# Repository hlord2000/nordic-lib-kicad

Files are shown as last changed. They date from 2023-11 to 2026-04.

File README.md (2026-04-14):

# Nordic Semiconductor KiCad Library




---
# A KiCad 10 library for all modern Nordic Semiconductor parts.
<p align="center">
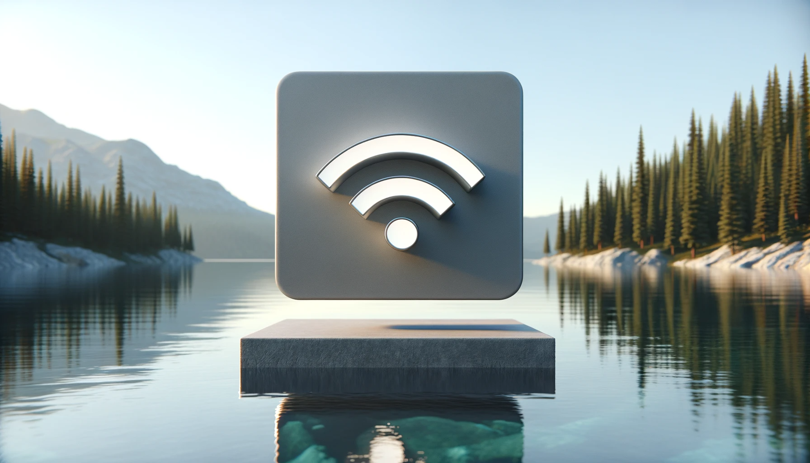
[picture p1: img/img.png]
centered image
  
</p>

KLC compliance is established using KiCad's official scripts within the "kicad-library-utils" folder and the "lib_check.sh" script

Compliance for the purposes of this library is defined as zero errors for footprints and symbols. Reasonable warnings about pin position or names may be accepted.

## Installation instructions

Open the KiCad Plugin and Content Manager (PCM), click "Manage..." in the top right, and add the following URL to your list of repositories:
```
https://raw.githubusercontent.com/hlord2000/hlord2000-kicad-repository/main/repository.json
```
Then, using the dropdown in the PCM, switch to "hlord2000's KiCad Repository" and click on the "Libraries" tab.

## Seeking pull-requests for any footprint/symbol/reference design block/3D model marked 🚧

 # nRF9 series - Cellular

| | Symbol | Footprint | Reference Design Block | 3D Model | KLC Compliant |
|---|---|---|---|---|---|
| [nRF9151](https://www.nordicsemi.com/products/nrf9151) LGA |✅|✅|🚧|✅|🚧|
| [nRF9161](https://www.nordicsemi.com/products/nrf9161) LGA |✅|✅|🚧|✅|🚧|
| [nRF9160](https://www.nordicsemi.com/products/nrf9160) LGA |✅|✅|🚧|✅|🚧|

 # nRF7 series - Wi-Fi

| | Symbol | Footprint | Reference Design Block | 3D Model | KLC Compliant |
|---|---|---|---|---|---|
| [nRF7002](https://www.nordicsemi.com/products/nrf7002) QFN |✅|✅|🚧|✅|🚧| 
| [nRF7002](https://www.nordicsemi.com/products/nrf7002) WLCSP |✅|✅|🚧|✅|🚧| 
| [nRF7001](https://www.nordicsemi.com/products/nrf7001) QFN |✅|✅|🚧|✅|🚧| 
| [nRF7000](https://www.nordicsemi.com/products/nrf7000) QFN |✅|✅|🚧|✅|🚧| 

# nRF54L series - Bluetooth Low Energy

| | Symbol | Footprint | Reference Design Block | 3D Model | KLC Compliant |
|---|---|---|---|---|---|
| [nRF54LM20A](https://www.nordicsemi.com/Products/nRF54LM20A) QFN-52 |✅|✅|✅|✅|🚧| 
| [nRF54LM20A](https://www.nordicsemi.com/Products/nRF54LM20A) FCCSP |✅|✅|✅|✅|🚧| 
| [nRF54L15](https://www.nordicsemi.com/products/nrf54l15) QFN-52 |✅|✅|✅|✅|🚧| 
| [nRF54L15](https://www.nordicsemi.com/products/nrf54l15) QFN-48 |✅|✅|✅|✅|🚧| 
| [nRF54L15](https://www.nordicsemi.com/products/nrf54l15) QFN-40 |✅|✅|✅|✅|🚧| 
| [nRF54L15](https://www.nordicsemi.com/products/nrf54l15) WLCSP |✅|✅|✅|✅|🚧| 
| [nRF54L10](https://www.nordicsemi.com/products/nrf54l10) QFN-52 |✅|✅|✅|✅|🚧| 
| [nRF54L10](https://www.nordicsemi.com/products/nrf54l10) QFN-48 |✅|✅|✅|✅|🚧| 
| [nRF54L10](https://www.nordicsemi.com/products/nrf54l10) QFN-40 |✅|✅|✅|✅|🚧| 
| [nRF54LV10A](https://www.nordicsemi.com/products/nrf54lv10) CSP-29 |✅|✅|🚧|✅|🚧| 
| [nRF54LV10A](https://www.nordicsemi.com/products/nrf54lv10) QFN-48 |✅|✅|🚧|✅|🚧| 
| [nRF54LS05A](https://www.nordicsemi.com/Products/nRF54LS05A) QFN-48 |✅|✅|🚧|✅|🚧| 
| [nRF54LS05B](https://www.nordicsemi.com/Products/nRF54LS05B) QFN-48 |✅|✅|🚧|✅|🚧| 
| [nRF54L05](https://www.nordicsemi.com/products/nrf54l05) QFN-52 |✅|✅|✅|✅|🚧| 
| [nRF54L05](https://www.nordicsemi.com/products/nrf54l05) QFN-48 |✅|✅|✅|✅|🚧| 
| [nRF54L05](https://www.nordicsemi.com/products/nrf54l05) QFN-40 |✅|✅|✅|✅|🚧| 

 # nRF53 series - Bluetooth Low Energy

| | Symbol | Footprint | Reference Design Block | 3D Model | KLC Compliant |
|---|---|---|---|---|---|
| [nRF5340](https://www.nordicsemi.com/products/nrf5340) aQFN |✅|✅|🚧|🚧|🚧| 
| [nRF5340](https://www.nordicsemi.com/products/nrf5340) WLCSP |✅|✅|🚧|🚧|🚧| 

 # nRF52 series - Bluetooth Low Energy

| | Symbol | Footprint | Reference Design Block | 3D Model | KLC Compliant |
|---|---|---|---|---|---|
| [nRF52840](https://www.nordicsemi.com/products/nrf52840) aQFN |✅|✅|🚧|✅|🚧| 
| [nRF52840](https://www.nordicsemi.com/products/nrf52840) WLCSP |✅|✅|🚧|🚧|🚧| 
| [nRF52840](https://www.nordicsemi.com/products/nrf52840) QFN |✅|✅|🚧|✅|🚧| 
| [nRF52833](https://www.nordicsemi.com/products/nrf52833) aQFN |✅|✅|🚧|🚧|🚧| 
| [nRF52833](https://www.nordicsemi.com/products/nrf52833) WLCSP |✅|✅|🚧|🚧|🚧| 
| [nRF52833](https://www.nordicsemi.com/products/nrf52833) QFN |✅|✅|🚧|✅|🚧| 
| [nRF52832](https://www.nordicsemi.com/products/nrf52832) WLCSP |✅|✅|🚧|🚧|🚧| 
| [nRF52832](https://www.nordicsemi.com/products/nrf52832) QFN |✅|✅|🚧|✅|🚧| 
| [nRF52820](https://www.nordicsemi.com/products/nrf52820) WLCSP |✅|✅|🚧|🚧|🚧| 
| [nRF52820](https://www.nordicsemi.com/products/nrf52820) QFN |✅|✅|🚧|✅|🚧| 
| [nRF52811](https://www.nordicsemi.com/products/nrf52811) WLCSP |✅|✅|🚧|✅|🚧| 
| [nRF52811](https://www.nordicsemi.com/products/nrf52811) QFN-32 |✅|✅|🚧|✅|🚧| 
| [nRF52811](https://www.nordicsemi.com/products/nrf52811) QFN-48 |✅|✅|🚧|✅|🚧| 
| [nRF52810](https://www.nordicsemi.com/products/nrf52810) WLCSP |✅|✅|🚧|✅|🚧| 
| [nRF52810](https://www.nordicsemi.com/products/nrf52810) QFN-32 |✅|✅|🚧|✅|🚧| 
| [nRF52810](https://www.nordicsemi.com/products/nrf52810) QFN-48 |✅|✅|🚧|✅|🚧| 
| [nRF52805](https://www.nordicsemi.com/products/nrf52805) WLCSP |✅|✅|🚧|✅|🚧| 

 # nRF52 series - Modules

| | Symbol | Footprint | Reference Design Block | 3D Model | KLC Compliant |
|---|---|---|---|---|---|
| [E73-2G4M08S1C](https://www.ebyte.com/product-view-news.html?id=787) LGA module |✅|✅|🚧|✅|🚧|
| [ISP1907-LL](https://www.insightsip.com/products/bluetooth-low-energy/isp1907) LGA module |✅|✅|🚧|✅|🚧|

 # nRF21 series - PA + LNA ICs

| | Symbol | Footprint | Reference Design Block | 3D Model | KLC Compliant |
|---|---|---|---|---|---|
| [nRF21540](https://www.nordicsemi.com/products/nrf21540) QFN |✅|✅|🚧|✅|✅| 

 # nRF53 series - Modules

| | Symbol | Footprint | Reference Design Block | 3D Model | KLC Compliant |
|---|---|---|---|---|---|
| [E83-2G4M03S](https://www.ebyte.com/product-view-news.html?id=1307) LGA module |✅|✅|🚧|✅|🚧|
| [ISP2053-AX](https://www.insightsip.com/products/bluetooth-low-energy-and-802-15-4/isp2053) LGA module |✅|✅|🚧|✅|🚧|

 # nRF54 series - Modules

| | Symbol | Footprint | Reference Design Block | 3D Model | KLC Compliant |
|---|---|---|---|---|---|
| BC15C LGA module |✅|✅|🚧|✅|🚧|
| BC15M LGA module |✅|✅|🚧|✅|🚧|
| BL54L15-453-000xxx LGA module |✅|✅|🚧|✅|🚧|
| BL54L10-453-000xxx LGA module |✅|✅|🚧|✅|🚧|
| BM15x LGA module |✅|✅|🚧|✅|🚧|
| BM20x LGA module |✅|✅|🚧|✅|🚧|

 # nPM Power Management ICs

| | Symbol | Footprint | Reference Design Block | 3D Model | KLC Compliant |
|---|---|---|---|---|---|
| [nPM6001](https://www.nordicsemi.com/products/nPM6001) WLCSP |✅|✅|🚧|🚧|✅| 
| [nPM2100](https://www.nordicsemi.com/products/nPM2100) WLCSP |✅|✅|🚧|✅|✅| 
| [nPM2100](https://www.nordicsemi.com/products/nPM2100) QFN |✅|✅|🚧|✅|✅| 
| [nPM1300](https://www.nordicsemi.com/products/nPM1300) WLCSP |✅|✅|🚧|🚧|✅| 
| [nPM1300](https://www.nordicsemi.com/products/nPM1300) QFN |✅|✅|🚧|✅|✅| 
| [nPM1100](https://www.nordicsemi.com/products/nPM1100) WLCSP |✅|✅|🚧|🚧|✅| 
| [nPM1100](https://www.nordicsemi.com/products/nPM1100) QFN |✅|✅|🚧|✅|✅|

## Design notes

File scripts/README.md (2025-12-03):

# Nordic Symbol Utilities

Utilities for parsing and generating KiCad symbols using the kiutils library.

## Setup

```bash
# From the repository root
uv venv
source .venv/bin/activate
uv pip install kiutils
```

## Usage

### List symbols in a library

```bash
python scripts/symbol_utils.py parse symbols/nordic-lib-kicad-nrf52.kicad_sym --list
```

### Parse a specific symbol

```bash
python scripts/symbol_utils.py parse symbols/nordic-lib-kicad-nrf52.kicad_sym --symbol nRF52805-CAXX --verbose
```

### Extract pin table

```bash
# Table format (default)
python scripts/symbol_utils.py pins symbols/nordic-lib-kicad-nrf52.kicad_sym --symbol nRF52805-CAXX

# CSV format
python scripts/symbol_utils.py pins symbols/nordic-lib-kicad-nrf52.kicad_sym --symbol nRF52805-CAXX --format csv

# JSON format
python scripts/symbol_utils.py pins symbols/nordic-lib-kicad-nrf52.kicad_sym --symbol nRF52805-CAXX --format json
```

### Extract complete symbol definition to JSON

```bash
python scripts/symbol_utils.py extract symbols/nordic-lib-kicad-nrf52.kicad_sym --symbol nRF52805-CAXX --output my_symbol.json
```

### Generate a symbol from JSON definition

```bash
python scripts/symbol_utils.py generate my_symbol.json --output my_symbol.kicad_sym
```

### Validate a symbol against KLC rules

```bash
python scripts/symbol_utils.py validate symbols/nordic-lib-kicad-nrf52.kicad_sym --symbol nRF52805-CAXX
```

## JSON Definition Format

The symbol definition JSON format for generation:

```json
{
  "name": "MyChip",
  "reference": "U",
  "footprint": "Package_QFP:LQFP-48_7x7mm_P0.5mm",
  "datasheet": "https://example.com/datasheet.pdf",
  "description": "My example chip",
  "keywords": "example chip mcu",
  "fp_filters": "LQFP?48*",
  "left_pins": [
    {
      "number": "1",
      "name": "PA0",
      "electrical_type": "bidirectional",
      "graphical_style": "line",
      "hidden": false,
      "alternates": [
        {"name": "ADC0", "electrical_type": "input", "graphical_style": "line"}
      ]
    }
  ],
  "right_pins": [],
  "top_pins": [
    {"number": "10", "name": "VDD", "electrical_type": "power_in", "graphical_style": "line", "hidden": false, "alternates": []}
  ],
  "bottom_pins": [
    {"number": "11", "name": "VSS", "electrical_type": "power_in", "graphical_style": "line", "hidden": false, "alternates": []}
  ]
}
```

### Pin Electrical Types

- `input` - Input pin
- `output` - Output pin
- `bidirectional` - Bidirectional I/O pin
- `power_in` - Power input (VDD, VCC)
- `power_out` - Power output (voltage regulator output)
- `passive` - Passive pin (resistors, capacitors, ground pads)
- `open_collector` - Open collector output
- `open_emitter` - Open emitter output
- `tri_state` - Tri-state output
- `unspecified` - Unspecified type
- `no_connect` - Not connected

### Pin Graphical Styles

- `line` - Standard line
- `inverted` - Inverted (bubble)
- `clock` - Clock input
- `inverted_clock` - Inverted clock
- `input_low` - Active low input
- `clock_low` - Active low clock
- `output_low` - Active low output
- `edge_clock_high` - Edge-triggered clock
- `non_logic` - Non-logic pin

## KLC Compliance

Generated symbols are designed to be KLC (KiCad Library Convention) compliant:

- S3.3: 10mil (0.254mm) stroke width on outlines
- S4.1: All pins on 100mil (2.54mm) grid
- Proper pin grouping by function (left/right/top/bottom)
- Standard property fields (Reference, Value, Footprint, Datasheet, Description)

Note: The KLC checker in kicad-library-utils may report some format warnings due to differences in KiCad version output formats. The generated symbols are functionally correct and compatible with KiCad.

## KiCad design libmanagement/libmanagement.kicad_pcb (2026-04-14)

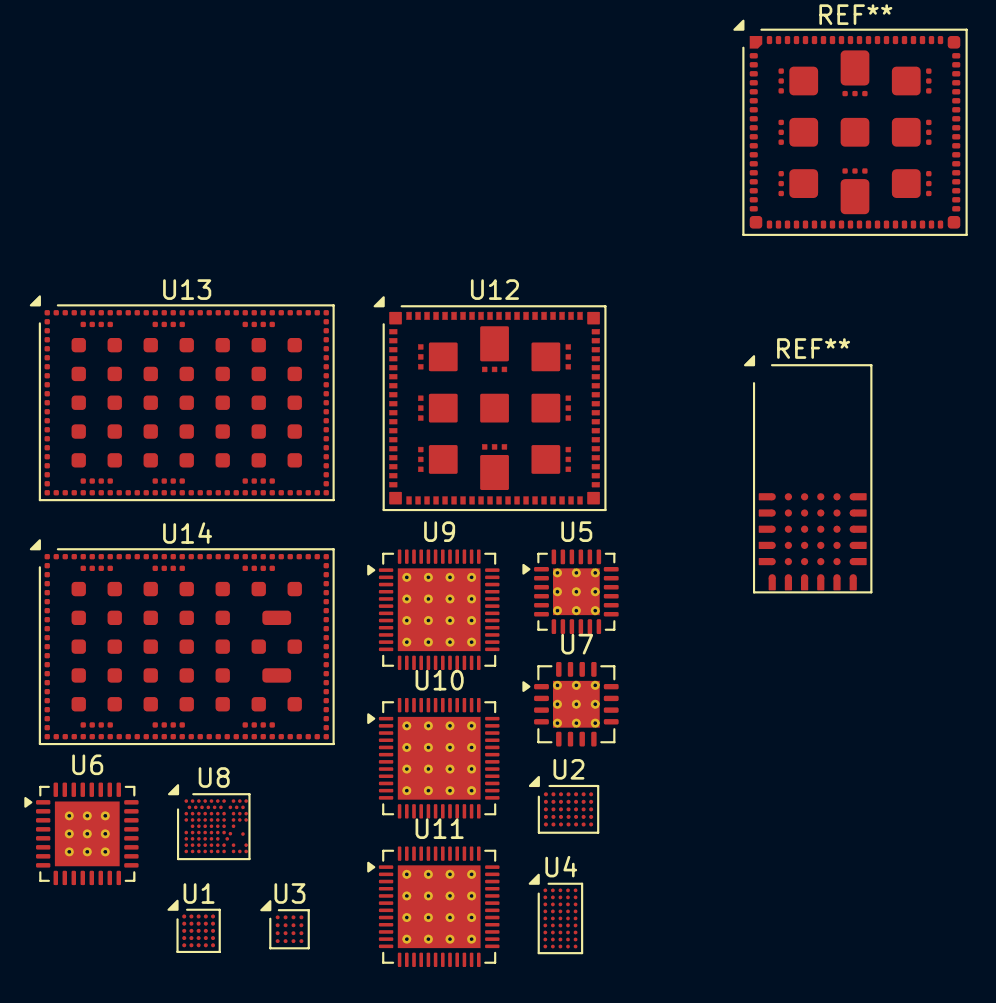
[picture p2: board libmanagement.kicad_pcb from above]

Board: 2 copper layers, 14 parts (0 on the bottom side), 21 nets, no tracks yet.

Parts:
U1: nPM1100-CAXX; BGA-25_5x5_2.075x2.075mm
U2: nPM1300-CAXX; BGA-35_7x5_3.077x2.3775mm
U3: nPM2100-CAXX; BGA-16_4x4_1.9175x1.8975mm
U4: nPM6001-CAXX; BGA-45_5x9_2.175x3.635mm
U5: nPM1100-QDXX; QFN-24-1EP_4x4mm_P0.5mm_EP2.6x2.6mm_ThermalVias
U6: nPM1300-QEXX; QFN-32-1EP_5x5mm_P0.5mm_EP3.6x3.6mm_ThermalVias
U7: nPM2100-QEXX; UQFN-16-1EP_4x4mm_P0.65mm_EP2.6x2.6mm_ThermalVias
U8: nRF7002-CEXX; BGA-90_10x9_3.7495x3.385mm
U9: nRF7000-QFXX; QFN-48-1EP_6x6mm_P0.4mm_EP4.6x4.6mm_ThermalVias
U10: nRF7001-QFXX; QFN-48-1EP_6x6mm_P0.4mm_EP4.6x4.6mm_ThermalVias
U11: nRF7002-QFXX; QFN-48-1EP_6x6mm_P0.4mm_EP4.6x4.6mm_ThermalVias
U12: nRF9151-LAXX; LGA_9151_12.1x11.1mm
U13: nRF9160-SIXX; LGA_9160_16.0x10.5mm
U14: nRF9161-SIXX; LGA_9161_16.0x10.5mm

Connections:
AVSS2: U7.11 (AVSS2), U7.16 (PVSS), U7.17 (EP)
unnamed: U1.D1 (VBAT), U1.D2 (VBAT)
unnamed: U1.B1 (VBUS), U1.B2 (VBUS)
unnamed: U1.A5 (VSS), U1.C4 (AVSS), U1.C5 (AVSS)
unnamed: U1.C1 (VSYS), U1.C2 (VSYS)
unnamed: U2.D1 (VBAT), U2.D2 (VBAT)
unnamed: U2.B1 (VBUS), U2.B2 (VBUS)
unnamed: U2.C1 (VSYS), U2.C2 (VSYS)
unnamed: U3.A4 (PVSS), U3.B1 (AVSS1), U3.B2 (AVSS2)
unnamed: U4.A3 (AVSS1_2), U4.B3 (RESERVED), U4.E5 (RESERVED), U4.F1 (VSS), U4.F2 (AVSS_ANA), U4.F4 (RESERVED), U4.G3 (RESERVED), U4.H2 (RESERVED), U4.H3 (AVSS0)
unnamed: U4.F3 (VIN_ANA), U4.G1 (VIN)
unnamed: U4.B4 (RESERVED), U4.C3 (RESERVED), U4.E4 (RESERVED), U4.G5 (VO0_IN), U4.H5 (VO0)
unnamed: U5.4 (AVSS), U5.25 (AVSS)
unnamed: U7.14 (VINT), U7.15 (VINT)
unnamed: U8.A1 (VSS), U8.A7 (GND), U8.A13 (GND), U8.A18 (GND), U8.A20 (GND), U8.C5 (GND), U8.C7 (GND), U8.C9 (GND), U8.C11 (GND), U8.C13 (GND), U8.D1 (GND), U8.D5 (GND), U8.D7 (GND), U8.D9 (GND), U8.D11 (GND), U8.D13 (GND), U8.D16 (GND), U8.D20 (GND), U8.E3 (GND), U8.E5 (GND), U8.E7 (GND), U8.E9 (GND), U8.E11 (GND), U8.E13 (GND), U8.F7 (GND), U8.F9 (GND), U8.F11 (GND), U8.F13 (GND), U8.H20 (GND), U8.J1 (BUCKVSSS), U8.J7 (GND), U8.K1 (BUCKVSS), U8.K20 (GND), U8.L3 (GND), U8.L9 (GND), U8.L18 (GND)
unnamed: U9.27 (BUCKVSS), U9.28 (BUCKVSS), U9.47 (VSS), U9.49 (EP)
unnamed: U10.8 (PAVDD1), U10.27 (BUCKVSS), U10.28 (BUCKVSS), U10.47 (VSS), U10.49 (EP)
unnamed: U11.27 (BUCKVSS), U11.28 (BUCKVSS), U11.47 (VSS), U11.49 (EP)
unnamed: U12.1 (GND), U12.7 (GND), U12.13 (GND), U12.15 (GND), U12.20 (GND), U12.25 (GND), U12.30 (GND), U12.34 (GND), U12.36 (GND), U12.38 (GND), U12.39 (GND), U12.40 (GND), U12.41 (GND), U12.43 (GND), U12.46 (GND), U12.51 (GND), U12.55 (GND), U12.60 (GND), U12.66 (GND), U12.71 (GND), U12.76 (GND), U12.105 (GND), U12.106 (GND), U12.107 (GND), U12.108 (GND), U12.109 (GND), U12.110 (GND), U12.111 (GND), U12.112 (GND), U12.113 (GND)
unnamed: U13.1 (GND_Shield), U13.5 (GND_Shield), U13.6 (GND_Shield), U13.7 (GND_Shield), U13.8 (GND_Shield), U13.9 (GND_Shield), U13.11 (GND_Shield), U13.14 (GND_Shield), U13.17 (GND_Shield), U13.21 (GND_Shield), U13.27 (GND_Shield), U13.31 (GND_Shield), U13.36 (GND_Shield), U13.41 (GND_Shield), U13.44 (GND_Shield), U13.47 (GND_Shield), U13.50 (GND_Shield), U13.52 (GND_Shield), U13.56 (GND_Shield), U13.60 (GND_Shield), U13.62 (GND_Shield), U13.63 (GND_Shield), U13.65 (GND_Shield), U13.66 (GND_Shield), U13.68 (GND_Shield), U13.69 (GND_Shield), U13.72 (GND_Shield), U13.74 (GND_Shield), U13.75 (GND_Shield), U13.76 (GND_Shield), U13.77 (GND_Shield), U13.78 (GND_Shield), U13.79 (GND_Shield), U13.80 (GND_Shield), U13.81 (GND_Shield), U13.82 (GND_Shield), U13.85 (GND_Shield), U13.90 (GND_Shield), U13.94 (GND_Shield), U13.98 (GND_Shield), U13.103 (VSS)
unnamed: U14.1 (GND_Shield), U14.5 (GND_Shield), U14.6 (GND_Shield), U14.7 (GND_Shield), U14.8 (GND_Shield), U14.9 (GND_Shield), U14.11 (GND_Shield), U14.14 (GND_Shield), U14.17 (GND_Shield), U14.21 (GND_Shield), U14.27 (GND_Shield), U14.31 (GND_Shield), U14.36 (GND_Shield), U14.41 (GND_Shield), U14.44 (GND_Shield), U14.47 (GND_Shield), U14.50 (GND_Shield), U14.52 (GND_Shield), U14.56 (GND_Shield), U14.60 (GND_Shield), U14.62 (GND_Shield), U14.63 (GND_Shield), U14.65 (GND_Shield), U14.66 (GND_Shield), U14.68 (GND_Shield), U14.69 (GND_Shield), U14.72 (GND_Shield), U14.74 (GND_Shield), U14.75 (GND_Shield), U14.76 (GND_Shield), U14.77 (GND_Shield), U14.78 (GND_Shield), U14.79 (GND_Shield), U14.80 (GND_Shield), U14.81 (GND_Shield), U14.82 (GND_Shield), U14.85 (GND_Shield), U14.90 (GND_Shield), U14.94 (GND_Shield), U14.98 (GND_Shield), U14.103 (VSS)

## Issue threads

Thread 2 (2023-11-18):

KiCad 7 unable to open file because it was created with a more recent version

FARLY7, 2023-11-18:
Installed the latest stable release of KiCad 7 (7.0.9), then followed the latest install instructions in the `main` branch. Received this error when loading the library in the schematic editor:

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

FARLY7, 2023-11-18:
Installing the latest nightly build worked. I think you should generate the library using the latest _stable_ release, not _nightly_?

hlord2000, 2023-12-09:
Closed by #5

Closed 2023-12-09.

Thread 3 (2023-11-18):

nRF9160-SIXX footprint is missing when README indicates it's included

FARLY7, 2023-11-18:
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

FARLY7, 2023-11-18:
It seems the footprint is there within the library, it just needs to be manually assigned?

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

However, after doing so, I get the following error in the board editor:

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

hlord2000, 2023-11-19:
Thank you for the issue reports! #2 as well! I will look into this over the next week or so.

hlord2000, 2023-12-09:
Fixed by #6

Closed 2023-12-09.

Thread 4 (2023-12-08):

Footprint for nRF9161

Arakistech, 2023-12-08:
Could you please add footprint for nRF9161? It is slightly different from nRF9160.

hlord2000, 2023-12-08:
Thanks for the issue! The 9161 is not yet available publicly--I cannot add footprints until they are available without NDA.

hlord2000, 2024-01-19:
Closed w/ https://github.com/hlord2000/nordic-lib-kicad/commit/e9b5a4e1483e48f4504e956a48b8dacd965c80cc

Closed 2024-01-19.

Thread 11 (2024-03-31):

Errors in nPM1100-QDXX symbol/footprint (due to errors in the product specification)

jeffc, 2024-03-31:
There are two errors in the footprint for the nPM1100-QDXX, which appear to be due to errors in the product specification which have not yet been corrected by Nordic:

 * Pin 4 should be labelled `AVSS` and connected to ground, not `NC`. This is an error in the pinout section on p.48 of the product specification. It is correct in the example schematics on pages 52, 53, and 54.
 * Pin 3 should be labelled `VOUTBSET0`, not `VOUTBSET2` (this is apparently a typo in the pinout sheet; there is no pin `VOUTBSET2`).

These errors have been acknowledged multiple times by Nordic engineers in the devzone ([example 1](https://devzone.nordicsemi.com/f/nordic-q-a/102701/npm1100-datasheet-pin-out), [example 2](https://devzone.nordicsemi.com/f/nordic-q-a/105055/npm1100-qda-pinout-documentation-fixed), [example 3](https://devzone.nordicsemi.com/f/nordic-q-a/106364/npm1100-product-specification-v1-3-errors)), but have not yet been corrected.

Closed 2024-04-01.

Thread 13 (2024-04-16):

Electrical type of pins is `Unspecified`

simplexion-blechschmidt, 2024-04-16:
Due to all pins on the (e.g. on the nRF9160-SIXX symbol) being `Unspecified`, the ERC is showing a lot of warnings and errors.
NRF provides a [pin assignment table](https://docs.nordicsemi.com/bundle/ps_nrf9160/page/pin.html) that also lists the function.

hlord2000, 2024-04-19:
Closed by
https://github.com/hlord2000/nordic-lib-kicad/pull/14

Closed 2024-04-19.

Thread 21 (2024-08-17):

only bga footprint？

yangxing844, 2024-08-17:
Hi, first of all, thank you for this  awesome collection! however I don't seem to find other footprint other than bga? the readme says QFN is supported, however I can not find it

hlord2000, 2024-08-17:
Hello, I'll take a look at this. All of the QFNs use KiCAD standard footprints.

hlord2000, 2024-09-24:
Refer to KiCAD 8 standard library of footprints

Closed 2024-09-24.

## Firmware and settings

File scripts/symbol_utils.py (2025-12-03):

#!/usr/bin/env python3
"""
Symbol Utilities for Nordic KiCad Library

This module provides utilities for parsing and generating KiCad symbols
using the kiutils library. It enables:
- Parsing existing symbols to extract pin tables
- Generating new symbols from pin table definitions
- Analyzing symbol structure for KLC compliance

Usage:
    # Parse a symbol and show its structure
    python symbol_utils.py parse symbols/nordic-lib-kicad-nrf52.kicad_sym --symbol nRF52805-CAXX

    # Extract pin table as CSV
    python symbol_utils.py pins symbols/nordic-lib-kicad-nrf52.kicad_sym --symbol nRF52805-CAXX --format csv

    # Generate a symbol from a pin table JSON
    python symbol_utils.py generate pin_table.json --output output.kicad_sym

    # Validate a symbol against KLC rules
    python symbol_utils.py validate symbols/nordic-lib-kicad-nrf52.kicad_sym --symbol nRF52805-CAXX
"""

import argparse
import json
import sys
import csv
import io
import subprocess
from dataclasses import dataclass, field, asdict
from pathlib import Path
from typing import Optional, List, Dict, Any, Tuple

from kiutils.symbol import SymbolLib, Symbol, SymbolPin, SymbolAlternativePin
from kiutils.items.common import Position, Effects, Font, Property, Fill, Stroke, Justify
from kiutils.items.syitems import SyRect


# Constants for symbol layout (KLC compliant)
# KLC S4.1: Pins must be on 100mil (2.54mm) grid
PIN_LENGTH = 2.54
PIN_SPACING = 2.54  # 100mil grid spacing
FONT_SIZE = 1.27
# KLC S3.3: Symbol outline should be 10mil (0.254mm)
RECT_STROKE_WIDTH = 0.254  # 10mil stroke width for KLC compliance
RECT_STROKE_TYPE = "default"
GRID_SIZE = 2.54  # 100mil grid


def snap_to_grid(value: float, grid: float = GRID_SIZE) -> float:
    """Snap a value to the nearest grid point (100mil by default)."""
    return round(value / grid) * grid


def parse_pin_name(name: str) -> Tuple[str, int, int]:
    """
    Parse a pin name into sortable components.

    Returns tuple of (category, port, pin_num) for sorting.
    Categories (lower number = higher priority/position):
    - 0: Crystal (XC1, XC2, XL1, XL2)
    - 1: GPIO Port 1 (P1.xx)
    - 2: GPIO Port 0 (P0.xx)
    - 3: GPIO Port 2+ (P2.xx, etc.)
    - 4: Antenna (ANT)
    - 5: Debug (RESET, SWDIO, SWDCLK)
    - 6: Power (VDD, VDDL, VSS, DCC)
    - 7: Decoupling (DEC*, CFLY*)
    - 9: Other
    """
    import re

    name_upper = name.upper().replace('~{', '').replace('}', '')

    # Crystal pins
    if name_upper.startswith('XC') or name_upper.startswith('XL'):
        match = re.search(r'(\d+)', name)
        num = int(match.group(1)) if match else 0
        return (0, 0, num)

    # GPIO pins - P<port>.<pin>
    gpio_match = re.match(r'P(\d+)\.(\d+)', name)
    if gpio_match:
        port = int(gpio_match.group(1))
        pin = int(gpio_match.group(2))
        # P1 first (category 1), then P0 (category 2), then P2+ (category 3)
        if port == 1:
            return (1, port, pin)
        elif port == 0:
            return (2, port, pin)
        else:
            return (3, port, pin)

    # Antenna
    if name_upper == 'ANT':
        return (4, 0, 0)

    # Debug pins
    if name_upper in ('RESET', 'SWDIO', 'SWDCLK', 'SWO'):
        order = {'RESET': 0, 'SWDIO': 1, 'SWDCLK': 2, 'SWO': 3}
        return (5, 0, order.get(name_upper, 99))

    # Power pins
    if name_upper.startswith('VDD') or name_upper == 'DCC':
        return (6, 0, 0 if name_upper.startswith('VDD') else 1)
    if name_upper.startswith('VSS'):
        return (6, 1, 0)

    # Decoupling caps
    if name_upper.startswith('DEC') or name_upper.startswith('CFLY'):
        order = {'DECRF': 0, 'DECA': 1, 'DECB': 2, 'DECD': 3, 'CFLYL': 4, 'CFLYH': 5}
        return (7, 0, order.get(name_upper, 99))

    # Everything else
    return (9, 0, 0)


def sort_pins_by_name(pins: List['PinDefinition']) -> List['PinDefinition']:
    """Sort pins by their name according to Nordic convention."""
    return sorted(pins, key=lambda p: parse_pin_name(p.name))


def parse_pin_number(number: str) -> Tuple[bool, int, str]:
    """
    Parse a pin number for sorting.

    Returns tuple of (is_numeric, numeric_value, alpha_part) for sorting.
    Handles both numeric (1, 2, 48) and BGA-style (A1, B2, F5) pin numbers.
    """
    import re

    # Try pure numeric first
    if number.isdigit():
        return (True, int(number), '')

    # Try BGA style (letter + number)
    match = re.match(r'([A-Z]+)(\d+)', number.upper())
    if match:
        letter_part = match.group(1)
        num_part = int(match.group(2))
        # Convert letter to number (A=0, B=1, etc.) for sorting
        letter_val = sum((ord(c) - ord('A')) * (26 ** i)
                        for i, c in enumerate(reversed(letter_part)))
        return (False, letter_val * 100 + num_part, letter_part)

    # Fallback
    return (False, 0, number)


def sort_pins_by_number(pins: List['PinDefinition']) -> List['PinDefinition']:
    """Sort pins by their pin number (numeric or BGA-style)."""
    return sorted(pins, key=lambda p: parse_pin_number(p.number))


@dataclass
class PinDefinition:
    """Represents a single pin definition for symbol generation."""
    number: str
    name: str
    electrical_type: str = "bidirectional"  # input, output, bidirectional, power_in, power_out, passive, etc.
    graphical_style: str = "line"  # line, inverted, clock, etc.
    hidden: bool = False
    alternates: List[Dict[str, str]] = field(default_factory=list)

    @classmethod
    def from_symbol_pin(cls, pin: SymbolPin) -> 'PinDefinition':
        """Create a PinDefinition from a kiutils SymbolPin."""
        alternates = []
        for alt in pin.alternatePins:
            alternates.append({
                'name': alt.pinName,
                'electrical_type': alt.electricalType,
                'graphical_style': alt.graphicalStyle
            })
        return cls(
            number=pin.number,
            name=pin.name,
            electrical_type=pin.electricalType,
            graphical_style=pin.graphicalStyle,
            hidden=pin.hide,
            alternates=alternates
        )

    def to_dict(self) -> Dict[str, Any]:
        """Convert to dictionary for JSON serialization."""
        return asdict(self)


@dataclass
class SymbolDefinition:
    """Represents a complete symbol definition for generation."""
    name: str
    reference: str = "U"
    footprint: str = ""
    datasheet: str = ""
    description: str = ""
    keywords: str = ""
    fp_filters: str = ""

    # Pin groups by side
    left_pins: List[PinDefinition] = field(default_factory=list)
    right_pins: List[PinDefinition] = field(default_factory=list)
    top_pins: List[PinDefinition] = field(default_factory=list)
    bottom_pins: List[PinDefinition] = field(default_factory=list)

    def to_dict(self) -> Dict[str, Any]:
        """Convert to dictionary for JSON serialization."""
        return {
            'name': self.name,
            'reference': self.reference,
            'footprint': self.footprint,
            'datasheet': self.datasheet,
            'description': self.description,
            'keywords': self.keywords,
            'fp_filters': self.fp_filters,
            'left_pins': [p.to_dict() for p in self.left_pins],
            'right_pins': [p.to_dict() for p in self.right_pins],
            'top_pins': [p.to_dict() for p in self.top_pins],
            'bottom_pins': [p.to_dict() for p in self.bottom_pins],
        }

    @classmethod
    def from_dict(cls, data: Dict[str, Any]) -> 'SymbolDefinition':
        """Create from dictionary (JSON deserialization)."""
        def parse_pins(pin_list: List[Dict]) -> List[PinDefinition]:
            return [PinDefinition(**p) for p in pin_list]

        return cls(
            name=data['name'],
            reference=data.get('reference', 'U'),
            footprint=data.get('footprint', ''),
            datasheet=data.get('datasheet', ''),
            description=data.get('description', ''),
            keywords=data.get('keywords', ''),
            fp_filters=data.get('fp_filters', ''),
            left_pins=parse_pins(data.get('left_pins', [])),
            right_pins=parse_pins(data.get('right_pins', [])),
            top_pins=parse_pins(data.get('top_pins', [])),
            bottom_pins=parse_pins(data.get('bottom_pins', [])),
        )


class SymbolParser:
    """Parses existing KiCad symbols and extracts information."""

    def __init__(self, library_path: str):
        self.library_path = Path(library_path)
        self.library: Optional[SymbolLib] = None

    def load(self) -> SymbolLib:
        """Load the symbol library."""
        if self.library is None:
            self.library = SymbolLib.from_file(str(self.library_path))
        return self.library

    def list_symbols(self) -> List[str]:
        """List all symbol names in the library."""
        lib = self.load()
        return [s.entryName for s in lib.symbols]

    def get_symbol(self, symbol_name: str) -> Optional[Symbol]:
        """Get a specific symbol by name."""
        lib = self.load()
        for symbol in lib.symbols:
            if symbol.entryName == symbol_name:
                return symbol
        return None

    def get_symbol_info(self, symbol_name: str) -> Dict[str, Any]:
        """Get detailed information about a symbol."""
        symbol = self.get_symbol(symbol_name)
        if symbol is None:
            return {}

        info = {
            'name': symbol.entryName,
            'in_bom': symbol.inBom,
            'on_board': symbol.onBoard,
            'properties': {},
            'units': [],
            'total_pins': 0,
        }

        # Extract properties
        for prop in symbol.properties:
            info['properties'][prop.key] = prop.value

        # Extract unit information
        for unit in symbol.units:
            unit_info = {
                'id': unit.libId,
                'pin_count': len(unit.pins),
                'graphic_items': len(unit.graphicItems),
            }
            info['units'].append(unit_info)
            info['total_pins'] += len(unit.pins)

        return info

    def extract_pins(self, symbol_name: str) -> List[PinDefinition]:
        """Extract all pins from a symbol."""
        symbol = self.get_symbol(symbol_name)
        if symbol is None:
            return []

        pins = []
        for unit in symbol.units:
            for pin in unit.pins:
                pins.append(PinDefinition.from_symbol_pin(pin))

        return pins

    def extract_pin_table(self, symbol_name: str) -> List[Dict[str, Any]]:
        """Extract pins as a flat table (for CSV export)."""
        pins = self.extract_pins(symbol_name)
        table = []
        for pin in pins:
            row = {
                'number': pin.number,
                'name': pin.name,
                'electrical_type': pin.electrical_type,
                'graphical_style': pin.graphical_style,
                'hidden': pin.hidden,
                'alternates': '; '.join([f"{a['name']}:{a['electrical_type']}" for a in pin.alternates])
            }
            table.append(row)
        return table

    def infer_pin_sides(self, symbol_name: str) -> Dict[str, List[PinDefinition]]:
        """Infer which side each pin belongs to based on position and angle."""
        symbol = self.get_symbol(symbol_name)
        if symbol is None:
            return {'left': [], 'right': [], 'top': [], 'bottom': []}

        sides = {'left': [], 'right': [], 'top': [], 'bottom': []}

        for unit in symbol.units:
            for pin in unit.pins:
                pin_def = PinDefinition.from_symbol_pin(pin)
                angle = pin.position.angle if pin.position.angle is not None else 0

                # Angle 0 = pointing right (pin on left side)
                # Angle 180 = pointing left (pin on right side)
                # Angle 90 = pointing up (pin on bottom)
                # Angle 270 = pointing down (pin on top)
                if angle == 0:
                    sides['left'].append(pin_def)
                elif angle == 180:
                    sides['right'].append(pin_def)
                elif angle == 90:
                    sides['bottom'].append(pin_def)
                elif angle == 270:
                    sides['top'].append(pin_def)
                else:
                    # Default to left for unusual angles
                    sides['left'].append(pin_def)

        return sides


class SymbolGenerator:
    """Generates KiCad symbols from definitions."""

    def __init__(self):
        self.generator_name = "nordic_symbol_utils"

    def create_symbol(self, definition: SymbolDefinition) -> Symbol:
        """Create a Symbol from a SymbolDefinition."""
        symbol = Symbol()
        symbol.entryName = definition.name
        symbol.inBom = True
        symbol.onBoard = True

        # Create standard properties
        symbol.properties = [
            self._create_property("Reference", definition.reference, 0, 0, 0),
            self._create_property("Value", definition.name, 0, -2.54, 1),
            self._create_property("Footprint", definition.footprint, 0, -5.08, 2, hide=True),
            self._create_property("Datasheet", definition.datasheet, 0, -7.62, 3, hide=True),
            self._create_property("Description", definition.description, 0, -10.16, 4, hide=True),
        ]

        if definition.keywords:
            symbol.properties.append(
                self._create_property("ki_keywords", definition.keywords, 0, 0, None, hide=True)
            )
        if definition.fp_filters:
            symbol.properties.append(
                self._create_property("ki_fp_filters", definition.fp_filters, 0, 0, None, hide=True)
            )

        # Create the unit with pins and rectangle
        unit = self._create_unit(definition)
        symbol.units.append(unit)

        return symbol

    def _create_property(self, key: str, value: str, x: float, y: float,
                        prop_id: Optional[int] = None, hide: bool = False) -> Property:
        """Create a property with standard formatting."""
        prop = Property()
        prop.key = key
        prop.value = value
        prop.id = prop_id
        prop.position = Position(X=x, Y=y, angle=0)
        prop.effects = Effects(
            font=Font(width=FONT_SIZE, height=FONT_SIZE),
            hide=hide
        )
        return prop

    def _create_unit(self, definition: SymbolDefinition, sort_pins: bool = True) -> Symbol:
        """Create a symbol unit with pins and graphics (KLC compliant).

        Args:
            definition: The symbol definition with pins organized by side
            sort_pins: If True, sort pins by name within each side
        """
        unit = Symbol()
        unit.entryName = definition.name
        unit.unitId = 1
        unit.styleId = 0

        # Sort pins by name if requested
        left_pins = sort_pins_by_name(definition.left_pins) if sort_pins else definition.left_pins
        right_pins = sort_pins_by_name(definition.right_pins) if sort_pins else definition.right_pins
        top_pins = sort_pins_by_name(definition.top_pins) if sort_pins else definition.top_pins
        bottom_pins = sort_pins_by_name(definition.bottom_pins) if sort_pins else definition.bottom_pins

        # Calculate dimensions based on pin counts
        # Count only visible pins for spacing calculation
        left_count = len([p for p in left_pins if not p.hidden])
        right_count = len([p for p in right_pins if not p.hidden])
        top_count = len([p for p in top_pins if not p.hidden])
        bottom_count = len([p for p in bottom_pins if not p.hidden])

        # Calculate rectangle dimensions - ensure grid alignment
        vertical_pins = max(left_count, right_count)
        horizontal_pins = max(top_count, bottom_count)

        # Calculate minimum dimensions and snap to grid
        # Height: need space for all vertical pins plus padding
        min_height = snap_to_grid(max(vertical_pins * PIN_SPACING + 2 * PIN_SPACING, 10.16))
        # Width: need space for all horizontal pins plus padding
        min_width = snap_to_grid(max(horizontal_pins * PIN_SPACING + 4 * PIN_SPACING, 15.24))

        rect_half_height = snap_to_grid(min_height / 2)
        rect_half_width = snap_to_grid(min_width / 2)

        # Create rectangle with KLC-compliant stroke width
        rect = SyRect()
        rect.start = Position(X=-rect_half_width, Y=rect_half_height)
        rect.end = Position(X=rect_half_width, Y=-rect_half_height)
        rect.stroke = Stroke(width=RECT_STROKE_WIDTH, type=RECT_STROKE_TYPE)
        rect.fill = Fill(type="background")
        unit.graphicItems.append(rect)

        # Calculate pin positions - ensure grid alignment
        # KLC S4.1: All pins must be on 100mil (2.54mm) grid

        # Left pins (pointing right, angle=0)
        # Start from top, working down
        left_x = snap_to_grid(-rect_half_width - PIN_LENGTH)
        left_y_start = snap_to_grid(rect_half_height - PIN_SPACING)
        self._add_pins_to_unit_positioned(unit, left_pins,
                                          base_x=left_x,
                                          start_y=left_y_start,
                                          angle=0,
                                          direction='vertical')

        # Right pins (pointing left, angle=180)
        right_x = snap_to_grid(rect_half_width + PIN_LENGTH)
        right_y_start = snap_to_grid(rect_half_height - PIN_SPACING)
        self._add_pins_to_unit_positioned(unit, right_pins,
                                          base_x=right_x,
                                          start_y=right_y_start,
                                          angle=180,
                                          direction='vertical')

        # Top pins (pointing down, angle=270)
        # Center horizontally
        top_width_needed = len([p for p in top_pins if not p.hidden]) * PIN_SPACING
        top_x_start = snap_to_grid(-top_width_needed / 2 + PIN_SPACING / 2)
        top_y = snap_to_grid(rect_half_height + PIN_LENGTH)
        self._add_pins_to_unit_positioned(unit, top_pins,
                                          base_x=top_x_start,
                                          start_y=top_y,
                                          angle=270,
                                          direction='horizontal')

        # Bottom pins (pointing up, angle=90)
        # Center horizontally
        bottom_width_needed = len([p for p in bottom_pins if not p.hidden]) * PIN_SPACING
        bottom_x_start = snap_to_grid(-bottom_width_needed / 2 + PIN_SPACING / 2)
        bottom_y = snap_to_grid(-rect_half_height - PIN_LENGTH)
        self._add_pins_to_unit_positioned(unit, bottom_pins,
                                          base_x=bottom_x_start,
                                          start_y=bottom_y,
                                          angle=90,
                                          direction='horizontal')

        return unit

    def _add_pins_to_unit_positioned(self, unit: Symbol, pins: List[PinDefinition],
                                      base_x: float, start_y: float, angle: float,
                                      direction: str) -> None:
        """Add pins to unit with proper positioning for hidden pins.

        Hidden pins are placed at the same position as the previous visible pin.
        This ensures stacked pins (like multiple VSS) share the same location.
        """
        x = snap_to_grid(base_x)
        y = snap_to_grid(start_y)
        last_visible_x = x
        last_visible_y = y

        for pin_def in pins:
            if pin_def.hidden:
                # Hidden pins go at the same position as the last visible pin
                pin = self._create_pin(pin_def, last_visible_x, last_visible_y, angle)
            else:
                pin = self._create_pin(pin_def, x, y, angle)
                last_visible_x = x
                last_visible_y = y
                # Only advance position for visible pins
                if direction == 'vertical':
                    y = snap_to_grid(y - PIN_SPACING)
                else:
                    x = snap_to_grid(x + PIN_SPACING)

            unit.pins.append(pin)

    def _add_pins_to_unit(self, unit: Symbol, pins: List[PinDefinition],
                         start_x: float, start_y: float, angle: float,
                         direction: str) -> None:
        """Add a list of pins to a unit (KLC S4.1: grid-aligned). DEPRECATED."""
        x, y = snap_to_grid(start_x), snap_to_grid(start_y)

        for pin_def in pins:
            pin = self._create_pin(pin_def, x, y, angle)
            unit.pins.append(pin)

            if direction == 'vertical':
                y = snap_to_grid(y - PIN_SPACING)
            else:
                x = snap_to_grid(x + PIN_SPACING)

    def _create_pin(self, pin_def: PinDefinition, x: float, y: float, angle: float) -> SymbolPin:
        """Create a SymbolPin from a PinDefinition (KLC compliant)."""
        pin = SymbolPin()
        pin.electricalType = pin_def.electrical_type
        pin.graphicalStyle = pin_def.graphical_style
        # Ensure positions are grid-aligned (KLC S4.1)
        pin.position = Position(X=snap_to_grid(x), Y=snap_to_grid(y), angle=angle)
        pin.length = PIN_LENGTH
        pin.name = pin_def.name
        pin.number = pin_def.number
        pin.hide = pin_def.hidden

        # Set effects for name and number
        pin.nameEffects = Effects(font=Font(width=FONT_SIZE, height=FONT_SIZE))
        pin.numberEffects = Effects(font=Font(width=FONT_SIZE, height=FONT_SIZE))
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

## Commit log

2023-06-09 Added footprints for nPM1100, nRF21540, nRF7002, nRF5340 WLCSP.
2023-07-21 Added libmanagement and continued creating symbols.
    [libmanagement.kicad_pcb, libmanagement.kicad_sch]
2023-07-22 Added footprints that exist in KiCAD already.
2023-07-24 Fixed duplication of efforts w.r.t. QFN footprints already in KiCAD 7. Finalized aQFN for 5340. Added 7001 footprint and symbol. Updated README to reflect changes.
2023-07-24 Added WLCSP footprint for nRF52840
2023-07-24 Added WLCSP footprint for nPM1300
2023-07-24 Added LGA footprint for nRF9160
2023-07-24 Added WLCSP footprint for nPM6001
2023-07-24 Added nRF52832 WLCSP footprint
2023-07-24 Added nRF52833 WLCSP footprint
2023-07-24 Added nRF52811/nRF52810 WLCSP footprint and nRF52820 WLCSP footprint
2023-07-24 Added aQFN footprint reference for nRF52833
2023-07-24 Fixed broken footprints
2023-09-23 Modified nPM1100/nPM1300 to get closer to KLC compliance. Added lib_check to check all symbols and footprints.
2023-10-07 modified pin length for nrf53
2023-11-14 nRF7000: Symbol Definition
    Added symbol definition for nRF7000, using KiCAD Library QFN footprint.
2023-12-09 symbols: revert to stable version (7.0)
    Reverted symbols in nRF5 and nRF7 libraries to use
    stable KiCAD versions.
    Per: https://github.com/hlord2000/nordic-lib-kicad/issues/2
2023-12-09 symbols: fixed footprint assocations
    When the library is run through PCM actions,
    it has "PCM_" appended to the library name for
    footprints. This just adds "PCM_" to the beginning
    of all symbol assigned footprints.
    Fixes issue #3
2024-01-19 Added nRF9161 and fixed nRF9160 footprint
2024-03-10 lib: updated to KiCAD 8
    update paths for 3dmodels and readme to reference
    KiCAD 8
2024-03-10 lib: modified PCM version
    Fixed PCM script to allow KiCAD 8 release.
2024-03-10 footprints: fix nrf9161 alignment
    restore footprint model alignment to 0,0,0
2024-03-31 Correct npm1100 footprint errors (fixes #11)
2024-04-19 symbols: nrf91: added pin definitions
    Added pin definitions for nRF916X parts.
    Closes issue #13
2024-05-07 Add npm1100 QFN24 center pad (pin 25) as AVSS
    According to
    [this devzone answer](https://devzone.nordicsemi.com/f/nordic-q-a/110896/help-with-strange-npm1100-performance),
    the center pad should be connected to AVSS (ground). This is not
    documented directly in the product specification, only hinted at by the
    example schematics.
2024-05-07 Overlap pin 25 (EP) with corresponding AVSS pin and make it invisible
2024-05-23 nrf52: modules: add isp1907
    Add footprint and symbol for the ISP1907-LL,
    nRF52811 SiP from ISP.
2024-05-23 modules: isp: updated footprints
    Updated footprints for ISP LGAs fixing
    issue w/ new ISP1907 having spurious dimension in silkscreen
2024-06-03 device: nrf9151
    Add nRF9151 symbol and footprint
2024-06-03 footprints: nrf9160
    Small change to description of nrf9160 footprint
2024-07-10 Symbol updates, pin length, pin type
2024-07-13 nrf53: update 5340
    Updated nRF5340 symbol w/ datasheet link and
    KiCAD included aQFN footprint
2024-08-01 footprints: nrf91x: solder paste expansion
    Modified solder paste expansion values for improved
    solder performance, per internal ticket.
2024-08-14 devices: nrf7002: added CSP
    Adds CSP variant of nRF7002
2024-09-03 nrf53: modules: add E83-2G4M03S
    Adds the E83-2G4M03S module, available for assembly
    at JLCPCB
2024-09-30 symbols: npm1300: moved power pins
    Move power pins for easier routing
2024-10-10 device: nrf54: added fanstel modules
    Added fanstel modules for nRF54 series
2024-11-12 devices: add nRF54L series
    Adds nRF54L15, L10, and L05
2024-11-15 Updated PCM for better footprint name handling
2024-12-10 design_blocks: add nRF54L reference design blocks
    Adds nRF54L series design blocks, a KiCAD 9 pre-release feature
    [nRF54L15-CAAA Reference Design.kicad_sch, nRF54L15-QFAA Reference Design.kicad_sch]
2025-02-06 symbols: nrf52: reworked all for KLC compliance, pin types
2025-02-24 footprints: npm1300: added csp step file
2025-03-24 Moved design blocks, changed create_pcm_archive to accomodate design blocks
    [nRF54L15-CAAA_Reference_Design.kicad_sch, nRF54L15-QFAA_Reference_Design.kicad_sch]
2025-09-18 Added nRF54LM20A and reference design
    [nRF54LM20A-PAAA_Reference_Design.kicad_sch]
2025-10-24 Updated nRF9151 footprint to match reference design
2025-11-24 Removed trailing comma on PCM metadata template
    Removed trailing comma after GitHub username to fix import failed on KiCad PCM import.
2025-12-02 Add symbol utilities for parsing and generating KiCad symbols
    - Add symbol_utils.py with kiutils-based parsing/generation
    - Support extract/generate workflow with JSON definitions
    - KLC-compliant symbol generation (grid alignment, stroke width)
    - Pin table extraction (CSV, JSON, table formats)
    - KLC validation via kicad-library-utils integration
    - Update kicad-library-utils to master for KiCad 8/9 support
    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
2025-12-03 Updates to fix footprint mapping
2026-04-14 Generate Nordic footprints from spec
2026-04-14 Updates to move to auto-generated footprints
    [libmanagement.kicad_sch, nRF54L15-CAAA_Reference_Design.kicad_sch]
2026-04-14 Updates for nRF54LS05A/B
    [nRF54L15-CAXX_Reference_Design.kicad_sch, nRF54L15-QFXX_Reference_Design.kicad_sch, nRF54LM20A-PAXX_Reference_Design.kicad_sch]
2026-04-14 Updates to 3d models + dirs
    [libmanagement.kicad_pcb]
2026-09-14 Fix P2.03 pin number from 14 to 13 in symbol
